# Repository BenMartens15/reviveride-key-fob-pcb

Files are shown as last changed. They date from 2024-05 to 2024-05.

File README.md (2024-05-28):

# ReviveRide: Modernizing Vintage Autos
### Project Overview
ReviveRide was developed as a capstone project for the Computer Engineering Technology program at Conestoga College. The goal of ReviveRide is to bring features found on modern vehicles to older vehicles. The project provides a dash camera, backup camera, head unit touchscreen with Android Auto, blind spot object detection, and remote start in an all-in-one, easy to install kit.

### Key Fob
The key fob wirelessly sends a signal to the control module telling it to start the car.

This repo contains the schematic and PCB for the key fob. The firmware for the key fob can be found here: https://github.com/BenMartens15/reviveride-key-fob-firmware

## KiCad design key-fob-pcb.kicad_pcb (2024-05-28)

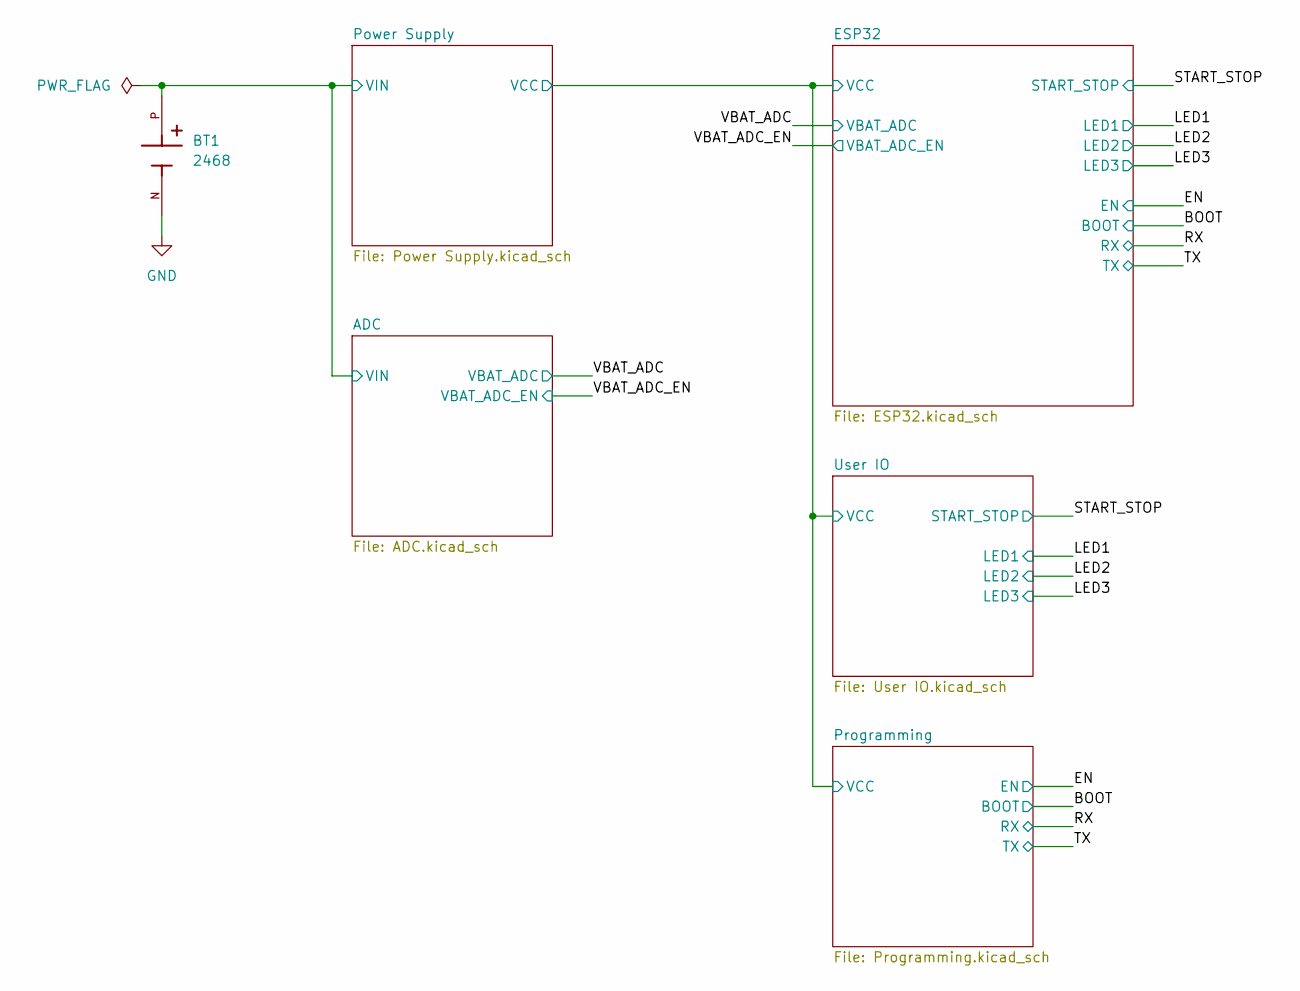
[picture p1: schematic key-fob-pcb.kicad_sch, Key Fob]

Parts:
BT1: 2468; BAT_2468; PARTREV D

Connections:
/ADC/VIN: BT1.P; also elsewhere on the board
GND: BT1.N; also elsewhere on the board

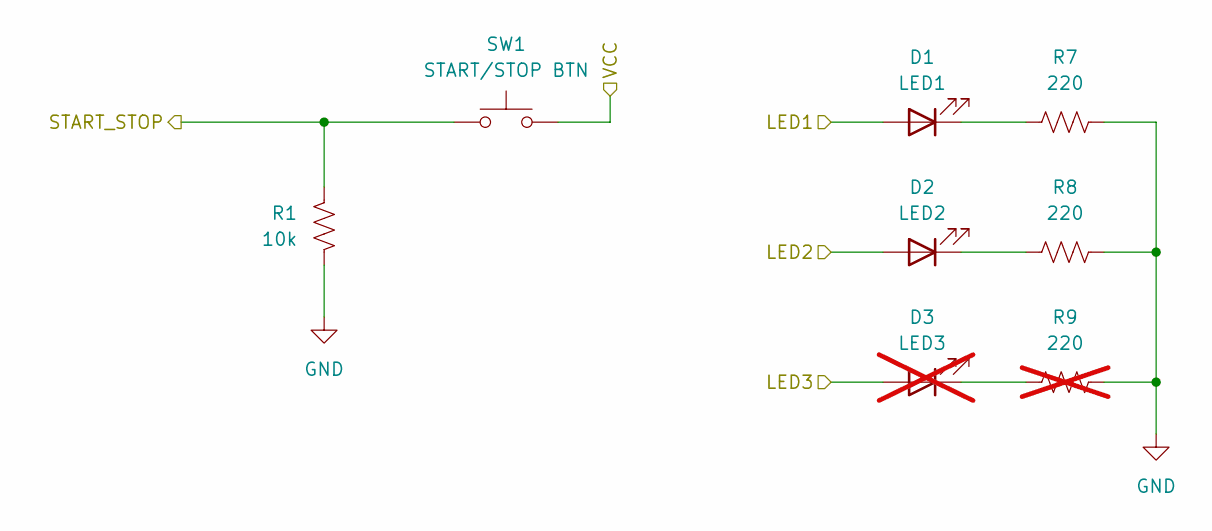
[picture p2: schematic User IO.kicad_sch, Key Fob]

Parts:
D1: LED1; LED_0603_1608Metric; MPN C128249
D2: LED2; LED_0603_1608Metric; MPN C2986018
D3: LED3; LED_0603_1608Metric; not fitted
R1: 10k; R_0603_1608Metric; MPN C2924175
R7, R8: 220; R_0603_1608Metric; MPN C844757
R9: 220; R_0603_1608Metric; not fitted
SW1: START/STOP BTN; SW_SPST_TL3305B

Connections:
/ESP32/VCC: SW1.1; also elsewhere on the board
/LED1: D1.2 (A); also elsewhere on the board
/LED2: D2.2 (A); also elsewhere on the board
/LED3: D3.2 (A); also elsewhere on the board
/START_STOP: R1.2, SW1.2; also elsewhere on the board
GND: R1.1, R7.1, R8.1, R9.1; also elsewhere on the board
unnamed: D1.1 (K), R7.2
unnamed: D2.1 (K), R8.2
unnamed: D3.1 (K), R9.2

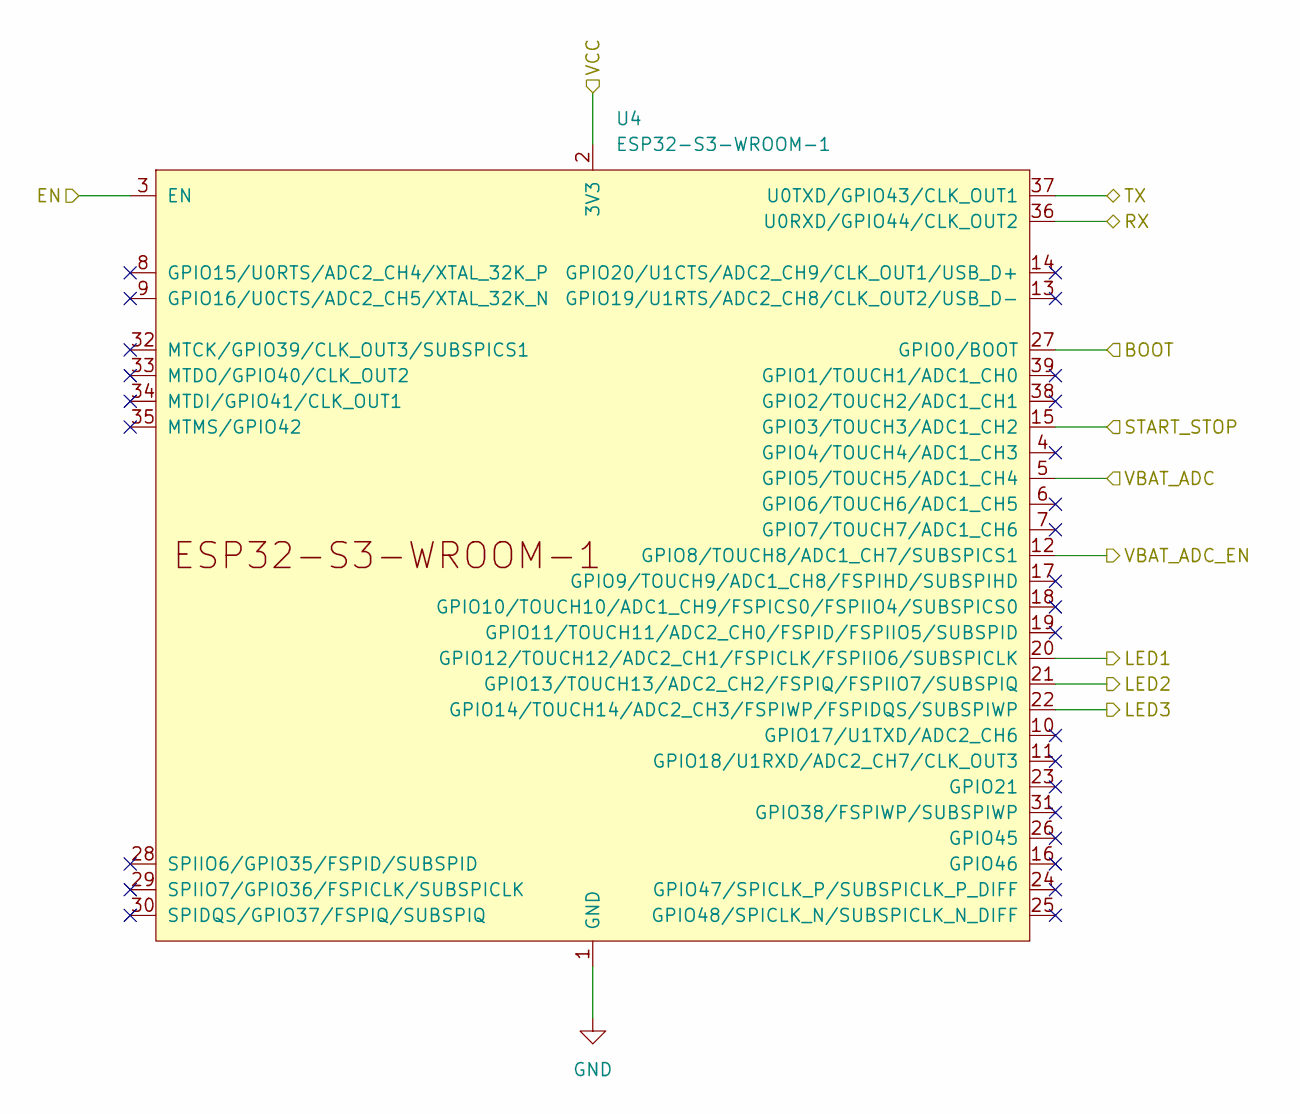
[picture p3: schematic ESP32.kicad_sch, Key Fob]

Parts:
U4: ESP32-S3-WROOM-1

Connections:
/BOOT: U4.27 (GPIO0/BOOT); also elsewhere on the board
/EN: U4.3 (EN); also elsewhere on the board
/ESP32/VCC: U4.2 (3V3); also elsewhere on the board
/LED1: U4.20 (GPIO12/TOUCH12/ADC2_CH1/FSPICLK/FSPIIO6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); also elsewhere on the board
/LED2: U4.21 (GPIO13/TOUCH13/ADC2_CH2/FSPIQ/FSPIIO7/S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); also elsewhere on the board
/LED3: U4.22 (GPIO14/TOUCH14/ADC2_CH3/FSPIWP/FSPIDQS/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); also elsewhere on the board
/RX: U4.36 (U0RXD/GPIO44/CLK_OUT2); also elsewhere on the board
/START_STOP: U4.15 (GPIO3/TOUCH3/ADC1_CH2); also elsewhere on the board
/TX: U4.37 (U0TXD/GPIO43/CLK_OUT1); also elsewhere on the board
/VBAT_ADC: U4.5 (GPIO5/TOUCH5/ADC1_CH4); also elsewhere on the board
/VBAT_ADC_EN: U4.12 (GPIO8/TOUCH8/ADC1_CH7/SUBSPICS1); also elsewhere on the board
GND: U4.1 (GND), U4.40 (GND), U4.41 (GND); also elsewhere on the board

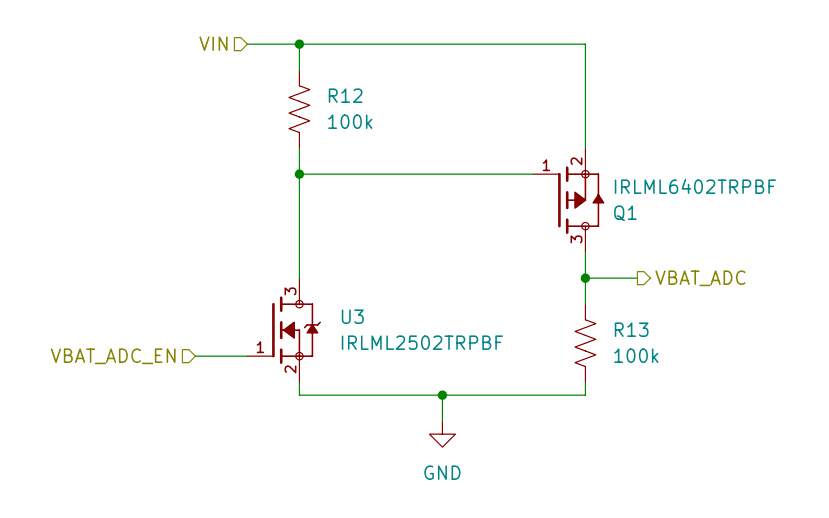
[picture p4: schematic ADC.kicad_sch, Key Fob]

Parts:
Q1: IRLML6402TRPBF; SOT95P237X112-3N; PARTREV N/A
R12, R13: 100k; R_0603_1608Metric; MPN C5369222
U3: IRLML2502TRPBF; SOT23; MPN C2589

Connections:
/ADC/VIN: Q1.2, R12.1; also elsewhere on the board
/VBAT_ADC: Q1.3, R13.1; also elsewhere on the board
/VBAT_ADC_EN: U3.1; also elsewhere on the board
GND: R13.2, U3.2; also elsewhere on the board
unnamed: Q1.1, R12.2, U3.3

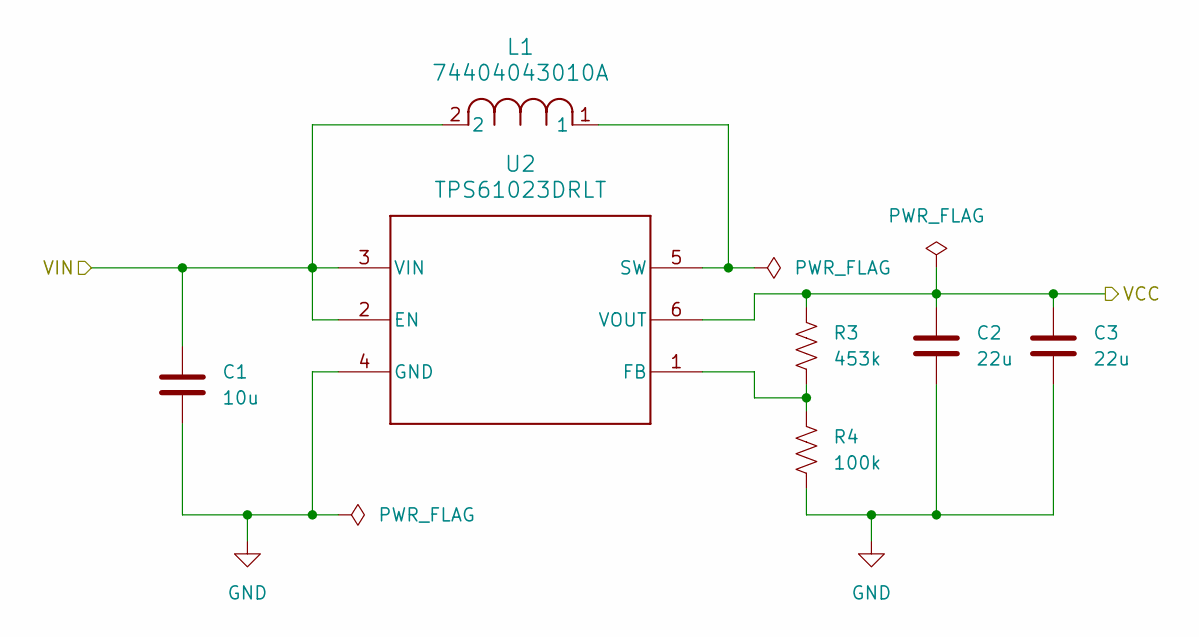
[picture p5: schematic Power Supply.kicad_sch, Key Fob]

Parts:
C1: 10u; C_0603_1608Metric; MPN C3009906
C2, C3: 22u; C_0603_1608Metric; MPN C2686246
L1: 74404043010A; IND_43010A_WRE
R3: 453k; C_0603_1608Metric; MPN C843903
R4: 100k; C_0603_1608Metric; MPN C844712
U2: TPS61023DRLT; DRL0006A; MPN C919459

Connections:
/ADC/VIN: C1.1, L1.2, U2.2 (EN), U2.3 (VIN); also elsewhere on the board
/ESP32/VCC: C2.1, C3.1, R3.1, U2.6 (VOUT); also elsewhere on the board
GND: C1.2, C2.2, C3.2, R4.2, U2.4 (GND); also elsewhere on the board
unnamed: R3.2, R4.1, U2.1 (FB)
unnamed: L1.1, U2.5 (SW)

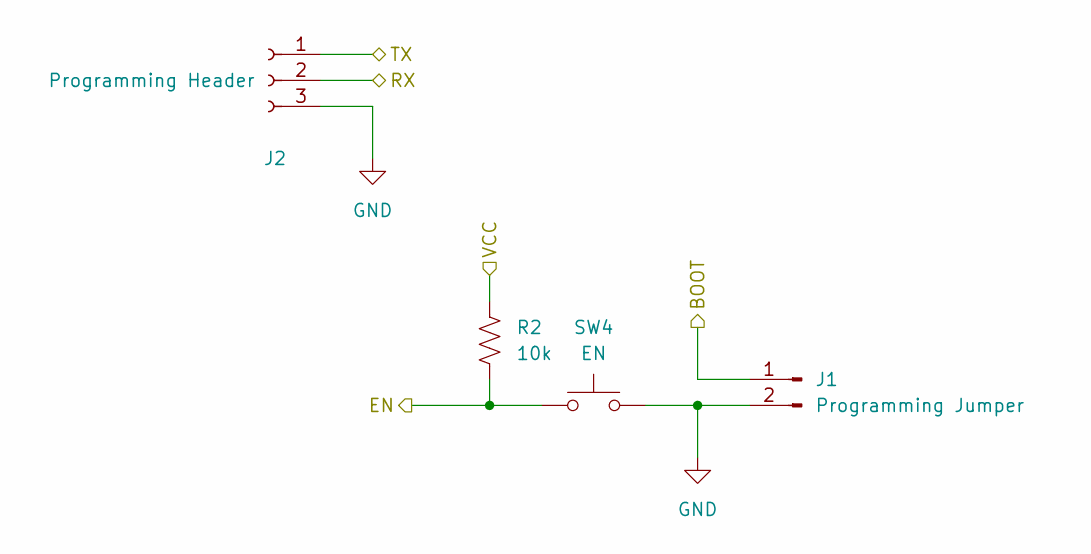
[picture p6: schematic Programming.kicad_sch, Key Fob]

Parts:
J1: Programming Jumper; SAMTEC_TSM-102-01-L-SH
J2: Programming Header; SAMTEC_TSM-103-01-L-SH-TR
R2: 10k; R_0603_1608Metric
SW4: EN; SW_SPST_TL3305B

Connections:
/BOOT: J1.1; also elsewhere on the board
/EN: R2.2; also elsewhere on the board
/ESP32/VCC: R2.1; also elsewhere on the board
/RX: J2.2; also elsewhere on the board
/TX: J2.1; also elsewhere on the board
GND: J1.2, J2.3; also elsewhere on the board

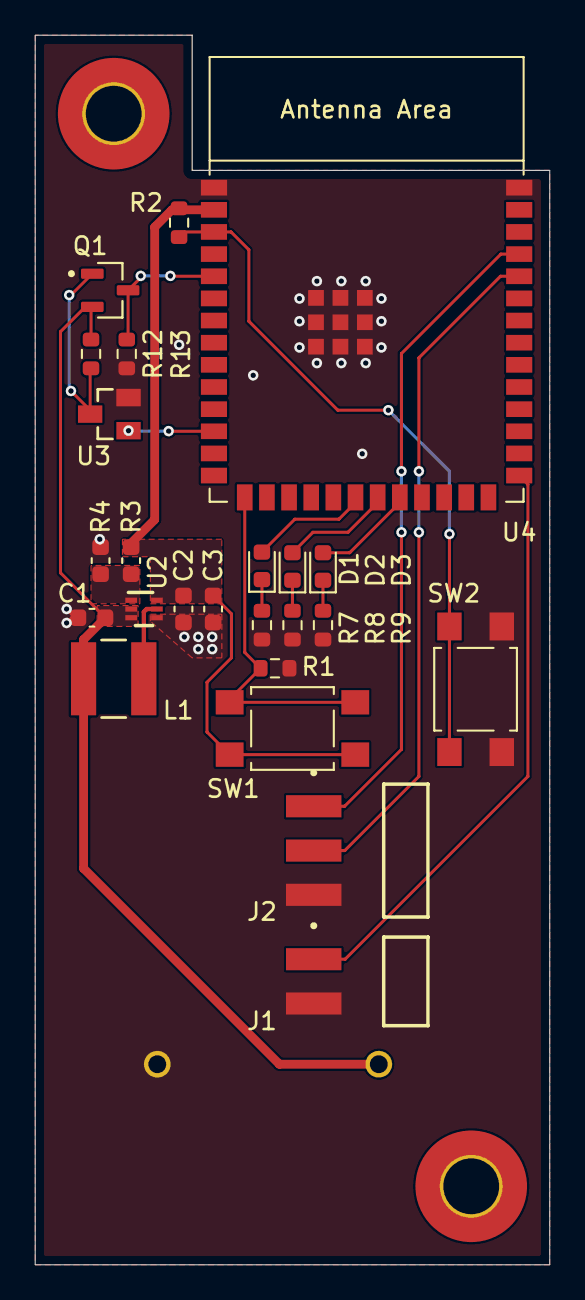
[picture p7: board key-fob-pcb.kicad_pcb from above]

Board: 2 copper layers, 29.5 x 70.5 mm, 25 parts (1 on the bottom side), 19 nets.

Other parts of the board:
SW2: EN; SW_SPST_TL3305B

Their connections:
/EN: SW2.2; also elsewhere on the board
GND: SW2.1; also elsewhere on the board

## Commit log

2023-10-18 basic schematic complete
    [ESP32.kicad_sch, Power Supply.kicad_sch, Programming.kicad_sch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]
2023-10-19 changed button to active high and added a few DNP buttons
    [User IO.kicad_sch, key-fob-pcb.kicad_sch]
2023-11-01 add ADC circuit, a few more DNP components, and assigned footprints
    [ADC.kicad_sch, ESP32.kicad_sch, Power Supply.kicad_sch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]
2023-11-02 create libraries folder for sharing external libs
    [ADC.kicad_sch, ESP32.kicad_sch, Power Supply.kicad_sch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]
2023-11-06 inital layout of components complete
    [ADC.kicad_sch, ESP32.kicad_sch, Power Supply.kicad_sch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]
2023-11-08 layout complete
    [ESP32.kicad_sch, Programming.kicad_sch, key-fob-pcb.kicad_pcb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]
2023-11-13 generate fab files
    [ADC.kicad_sch, ESP32.kicad_sch, Power Supply.kicad_sch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]
2023-11-13 minor changes
    [key-fob-pcb.kicad_pcb]
2023-11-23 replace GND heriarchical labels with GND symbols
    [ADC.kicad_sch, ESP32.kicad_sch, Power Supply.kicad_sch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]
2023-11-23 add author to each sheet
    [ADC.kicad_sch, ESP32.kicad_sch, Power Supply.kicad_sch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]
2024-01-12 add BOM files to git
    [bom.csv, designators.csv, positions.csv]
2024-02-09 add 3D models and generate STEP file for PCB
    [key-fob-pcb.kicad_pcb]
2024-02-09 switched to full-sized ESP32 S3 WROOM and redid PCB layout
    [ESP32.kicad_sch, Power Supply.kicad_sch, Programming.kicad_sch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]
2024-02-09 generate gerbers
    [bom.csv, designators.csv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]
2024-02-19 update 3D models and generate PCB step file
    [key-fob-pcb.kicad_pcb]
